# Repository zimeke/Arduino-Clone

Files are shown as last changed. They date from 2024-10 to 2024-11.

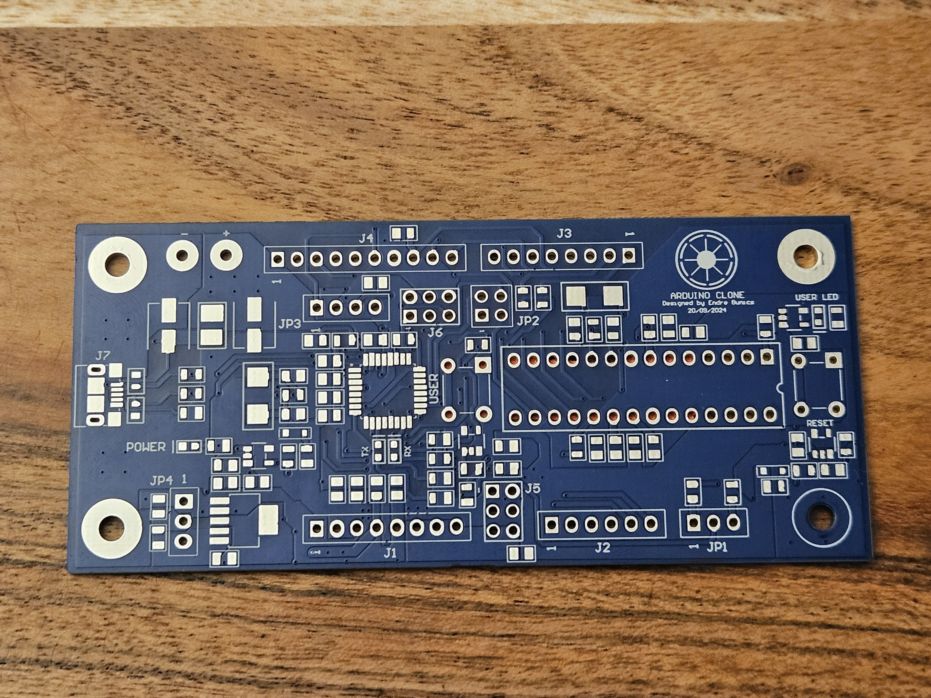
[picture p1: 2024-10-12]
Photos/Arduino Clone without components.jpg

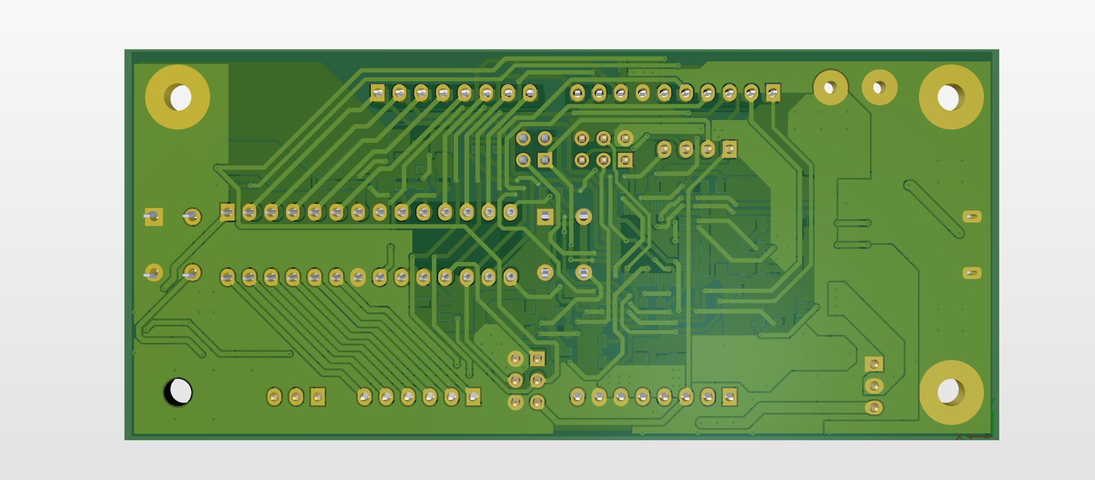
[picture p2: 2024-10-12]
3D_model_back.PNG

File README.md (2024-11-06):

# Arduino Clone
This project involves creating a microcontroller similar to the Arduino UNO. The design and implementation were based on the guidance provided by Robert Feranec (youtube/udemy educator). The project includes PCB layout design using Altium Designer, soldering the components, checking the soldered connections, programming, and testing the microcontroller.

Arduino Clone

## Designing PCB layout and 3D model in Altium Designer

I developed the PCB layout design and the board's 3D model using Altium Designer. All necessary documents for circuit manufacturing have been uploaded to the repository. For guidance on creating the schematic and PCB layout, I followed Robert Feranec's instructional videos.

Link to the guide:
https://www.udemy.com/course/learn-to-design-your-own-boards

3D_model_side
<p align="center">
  3D model in Altium Designer
</p>

## Soldering the components

Arduino Clone without components

<p align="center">
  PCB without components
</p>

After designing the PCB layout, I had the board manufactured by JLCPCB. I ordered the components from Digi-Key, which I soldered on the PCB by hand. For the soldering process, I used the following tools:
* Flux: EDSYN FL 22 R & Stannol 165018 F-SW 26
* Solder: STANNOL HF32
* Tweezers
* Soldering Station: Hakko FX888D
* Soldering Tip: Hakko T18-D24
* Desoldering Wire

(I worked with a soldering iron heated to 350 degrees Celsius.)

 tools
<p align="center">
  Tools used
</p>

Arduino Clone without connectors

I started with the soldering of the ATmega16U2 component, as it proved to be the most challenging. After soldering, I inspected the connections using a magnifying glass to check for any short circuits between the individual pins, followed by verification with a multimeter.

Next, I moved on to soldering smaller components, such as SOD-323 and 0603 size-code components. I used the following method for soldering these components:

1. I first applied a small amount of flux to one pad of the component.
2. Then, I placed solder on that pad.
3. After that, I applied more flux to the pad and soldered the component's corresponding lead on the pad where the solder had previously been applied.
4. Finally, I soldered the other lead(s) of the component.

To check if the component was properly soldered, I pushed one of its leads with the hot soldering iron tip. If the component did not move, it indicated that the other lead was secured, confirming that the connection had been made.

However, this method was not practical, because is some cases the solder mask came off during the pushing process.

After soldering all the components, I checked each soldered connection using a multimeter to ensure that all connections were properly made. Afterward, I soldered the connectors and checked them as well to ensure proper connections. Fortunately, all the soldered joints were correct, so no further adjustments were needed.

Arduino Clone compared to Arduino UNO
<p align="center">
  Arduino Clone compared to Arduino UNO
</p>

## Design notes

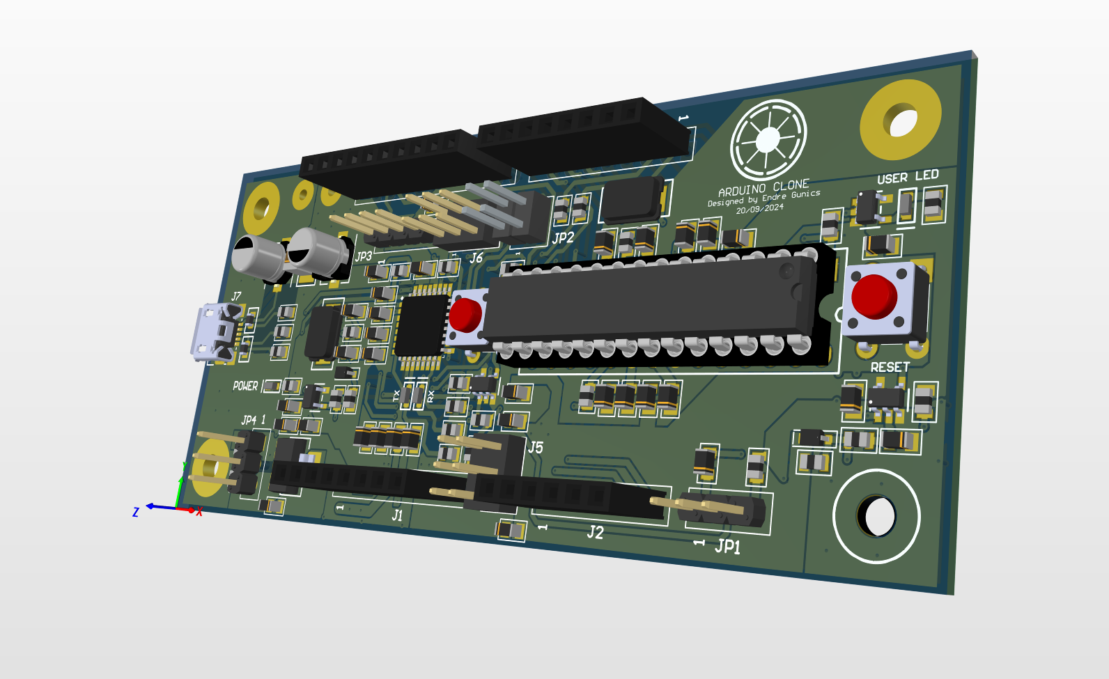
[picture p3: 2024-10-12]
3D_model_side.PNG

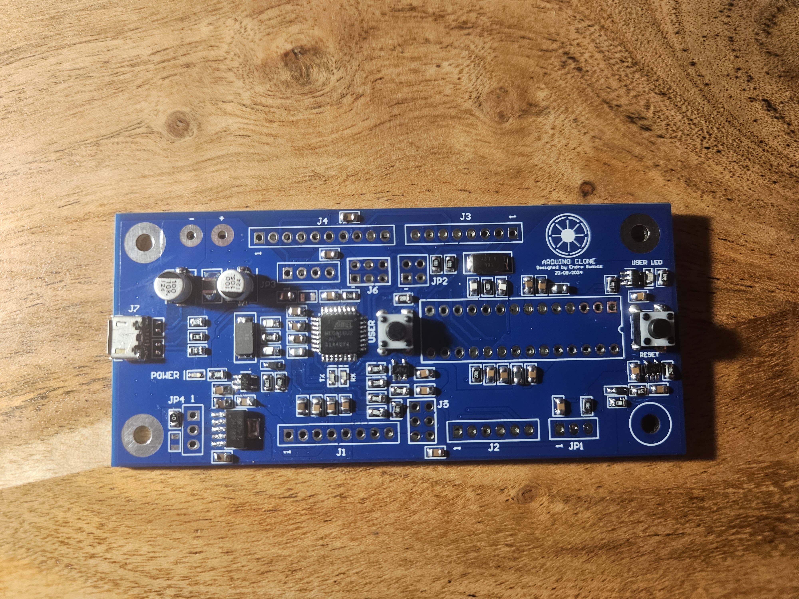
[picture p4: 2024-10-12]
Photos/Arduino Clone without connectors.jpg

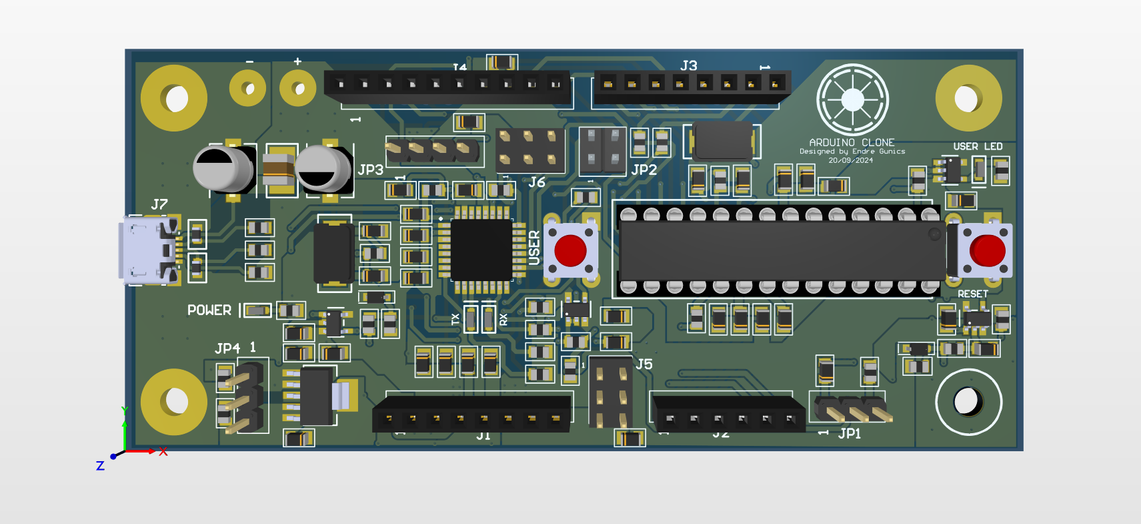
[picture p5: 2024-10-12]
3D_model_front.PNG

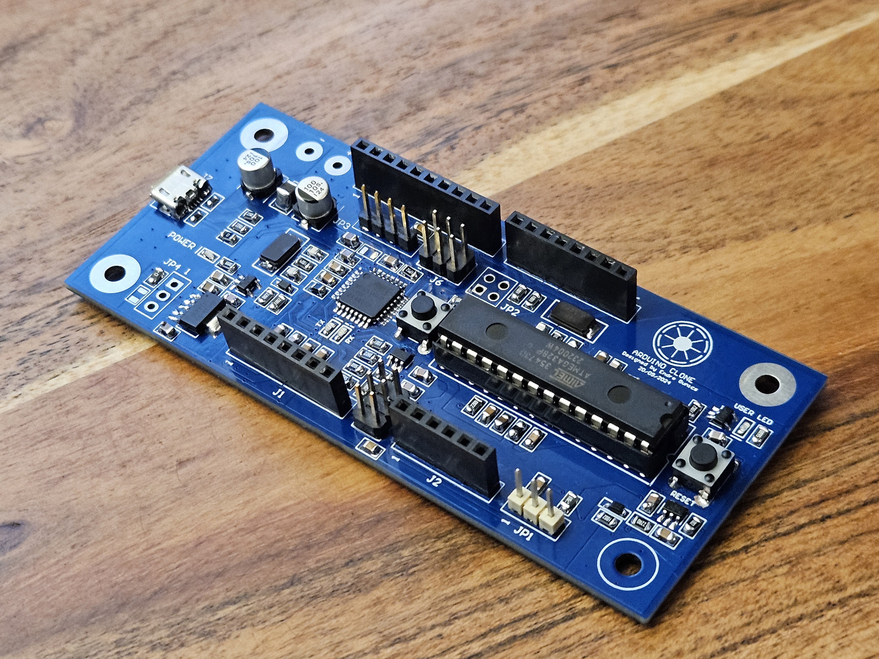
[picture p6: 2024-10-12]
Photos/Arduino Clone.jpg

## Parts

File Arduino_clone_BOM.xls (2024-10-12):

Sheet: Part List Report
# | Designator | Quantity | Comment | Description | Manufacturer 1 | Manufacturer Part Number 1 | Package / Case | Supplier 1 | Supplier Part Number 1 | Quantity
1 | C1, C2 | 2 | 100u / 10V | CAP ALUM 100UF 10V 20% SMD | Panasonic Electronic Components | EEE-1AA101WR | Radial, Can - SMD | Digi-Key | PCE3867CT-ND | 2
2 | C3, C12, C13, C19, C21, C22, C34 | 7 | 10uF / 16V | CAP CER 10UF 16V 20% X5R 0805 | TDK Corporation | C2012X5R1C106M125AC | 0805 (2012 Metric) | Digi-Key | 445-4115-1-ND | 7
3 | C4, C5, C6, C8, C11, C14, C15, C16, C17, C20, C23, C24, C26, C28, C29, C30, C31, C32, C33 | 19 | 100n | CAP CER 0.1UF 50V 10% X7R 0805 | TDK Corporation | C2012X7R1H104K085AA | 0805 (2012 Metric) | Digi-Key | 445-7534-1-ND | 19
4 | C7 | 1 | 1u | CAP CER 1UF 25V 10% X5R 0805 | TDK Corporation | C2012X5R1E105K125AA | 0805 (2012 Metric) | Digi-Key | 445-1419-1-ND | 1
5 | C9, C10, C25, C27 | 4 | 18p | CAP CER 18PF 50V 5% NP0 0805 | Kemet | C0805C180J5GACTU | 0805 (2012 Metric) | Digi-Key | 399-1112-1-ND | 4
6 | D1 | 1 | Green | LED SMARTLED GREEN 570NM 0603 | OSRAM Opto Semiconductors Inc | LG L29K-G2J1-24-Z | 0603 (1608 Metric) | Digi-Key | 475-2709-1-ND | 1
7 | D2, D3, D4 | 3 | Orange | LED SMARTLED ORANGE 606NM 0603 | OSRAM Opto Semiconductors Inc | LO L29K-H2K1-24-Z | 0603 (1608 Metric) | Digi-Key | 475-2740-1-ND | 3
8 | D5, D6 | 2 | BAT54HT1G | DIODE SCHOTTKY 30V 0.2A SOD323 | Fairchild Semiconductor | BAT54HT1G | SC-76, SOD-323 | Digi-Key | BAT54HT1GCT-ND | 2
9 | FB1, FB2, FB3 | 3 | MPZ2012S601AT000 | FERRITE CHIP BEAD 600 OHM SMD | TDK Corporation | MPZ2012S601AT000 | 0805 (2012 Metric) | Digi-Key | 445-2206-1-ND | 3
10 | J1, J3 | 2 | HDR FMALE 1x8 2.54mm | 08-WAY SIL VERT SOCKET L/FREE | Harwin Inc | M20-7820842 |  | Digi-Key | 952-1823-ND | 2
11 | J2 | 1 | HDR FMALE 1x6 2.54mm | 06-WAY SIL VERT SOCKET L/FREE | Harwin Inc | M20-7820646 |  | Digi-Key | 952-1809-ND | 1
12 | J4 | 1 | HDR FMALE 1x10 2.54mm | 10-WAY SIL VERT SOCKET L/FREE | Harwin Inc | M20-7821046 |  | Digi-Key | 952-1847-ND | 1
13 | J5, J6 | 2 | HDR 2x3 | CONN HEADER 6POS .100 STR 30AU | FCI | 67997-106HLF |  | Digi-Key | 609-3393-ND | 2
14 | J7 | 1 | 10118193-0001LF | CONN USB MICRO B RECPT SMT R/A | FCI | 10118193-0001LF |  | Digi-Key | 609-4616-1-ND | 1
15 | JP1, JP4 | 2 | HDR 1x3 | BERGSTIK II .100" SR STRAIGHT | FCI | 68000-103HLF |  | Digi-Key | 609-3461-ND | 2
16 | JP3 | 2 | HDR 1x4 | CONN HEADER 4POS .100 STR 15AU | FCI | 68002-204HLF |  | Digi-Key | 609-3369-ND | 2
17 | JP3 | 2 | HDR 1x4 | CONN HEADER 4POS .100 STR 15AU | FCI | 68001-204HLF |  | Digi-Key | 609-3402-ND | 2
18 | L1 | 1 | 2u2 / 2A | FIXED IND 2.2UH 2A 80 MOHM SMD | Kemet | L1210R2R2MDWIT | 1210 (3225 Metric) | Digi-Key | 399-9598-1-ND | 1
19 | LINK1, LINK2, LINK3 | 3 | LINK | CONN JUMPER SHORTING .100" GOLD | Sullins Connector Solutions | QPC02SXGN-RC |  | Digi-Key | S9337-ND | 3
20 | R1 | 1 | 100k | RES SMD 100K OHM 1% 1/8W 0805 | Yageo | RC0805FR-07100KL | 0805 (2012 Metric) | Digi-Key | 311-100KCRCT-ND | 1
21 | R2, R3, R15, R17, R22 | 5 | 560R | RES SMD 560 OHM 1% 1/8W 0805 | Yageo | RC0805FR-07560RL | 0805 (2012 Metric) | Digi-Key | 311-560CRCT-ND | 5
22 | R4, R14, R18, R19, R20, R21 | 6 | 10k | RES SMD 10K OHM 1% 1/8W 0805 | Yageo | RC0805FR-0710KL | 0805 (2012 Metric) | Digi-Key | 311-10.0KCRCT-ND | 6
23 | R5, R6, R7, R13, R23, R24, R25 | 7 | 22R | RES SMD 22 OHM 1% 1/8W 0805 | Yageo | RC0805FR-0722RL | 0805 (2012 Metric) | Digi-Key | 311-22.0CRCT-ND | 7
24 | R8 | 4 | 0R | RES 0.0 OHM 1/8W 0805 SMD | Yageo | RC0805JR-070RL | 0805 (2012 Metric) | Digi-Key | 311-0.0ARCT-ND | 4
25 | R9, R16 | 2 | 1M | RES SMD 1M OHM 1% 1/8W 0805 | Yageo | RC0805FR-071ML | 0805 (2012 Metric) | Digi-Key | 311-1.00MCRCT-ND | 2
26 | R10, R11, R12 | 3 | 1k | RES SMD 1K OHM 1% 1/8W 0805 | Yageo | RC0805FR-071KL | 0805 (2012 Metric) | Digi-Key | 311-1.00KCRCT-ND | 3
27 | SCKT FOR U1 | 1 | 28-DIP Socket | CONN IC DIP SOCKET 28POS TIN | 3M | 4828-3004-CP |  | Digi-Key | 3M5480-ND | 1
28 | SW1, SW2 | 2 | 1825910-6 | SWITCH TACTILE SPST-NO 0.05A 24V | TE Connectivity | 1825910-6 |  | Digi-Key | 450-1650-ND | 2
29 | U1 | 1 | ATMEGA328P-PU | IC MCU 8BIT 32KB FLASH 28DIP | Atmel | ATMEGA328P-PU | 28-DIP (0.300", 7.62mm) | Digi-Key | ATMEGA328P-PU-ND | 1
30 | U2 | 1 | ATMEGA16U2-AU | IC MCU 8BIT 16KB FLASH 32TQFP | Atmel | ATMEGA16U2-AU | 32-TQFP | Digi-Key | ATMEGA16U2-AU-ND | 1
31 | U3 | 1 | TL1963A-33DCQR | IC REG LDO 3.3V 1.5A SOT223-6 | Texas Instruments | TL1963A-33DCQR | SOT-223-6 | Digi-Key | 296-24534-1-ND | 1
32 | U4, U5, U6, U7 | 4 | SN74AHC1G09DBVR | IC GATE AND SGL 2INP SOT23-5 | Texas Instruments | SN74AHC1G09DBVR | SC-74A, SOT-753 | Digi-Key | 296-29202-1-ND | 4
33 | Y1, Y2 | 2 | ABM7-16.000MHZ-D2Y-T | CRYSTAL 16MHZ 18PF SMD | Abracon LLC | ABM7-16.000MHZ-D2Y-T | 2-SMD | Digi-Key | 535-9840-1-ND | 2
34 | Z1, Z2 | 2 | CG0603MLC-05E | VARISTOR 0603 | Bourns Inc. | CG0603MLC-05E | 0603 (1608 Metric) | Digi-Key | CG0603MLC-05ECT-ND | 2

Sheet: Project Information
Project Full Path | S:\FEDEVEL\28pins\V1I1\28Pins_Project_V1I1.PrjPcb
Project Filename | 28Pins_Project_V1I1.PrjPcb
Variant Name | 5V/3V3
Data-Source Filename | 28Pins_Project_V1I1.PrjPcb
Data-Source Full Path | S:\FEDEVEL\28pins\V1I1\28Pins_Project_V1I1.PrjPcb
Title | 28Pins_Project_V1I1.PrjPcb
Total Quantity | 95
Report Time | 4:53:29 PM
Report Date | 4/7/2015
Report Date & Tine | 4/7/2015 4:53:29 PM
Output Name | 28Pins Component reference grouped BOM
Output Type | BOM_PartType
Output Generator Name | BOM
Output Generator Description | Bill of Materials

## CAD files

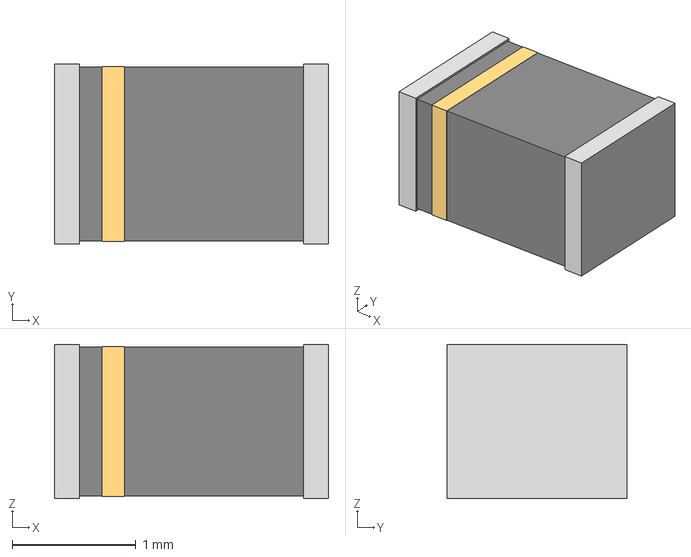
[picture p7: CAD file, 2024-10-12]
3D_models_for_Altium_Designer/CAP_2012_TDK.step
2.21 x 1.45 x 1.25 mm

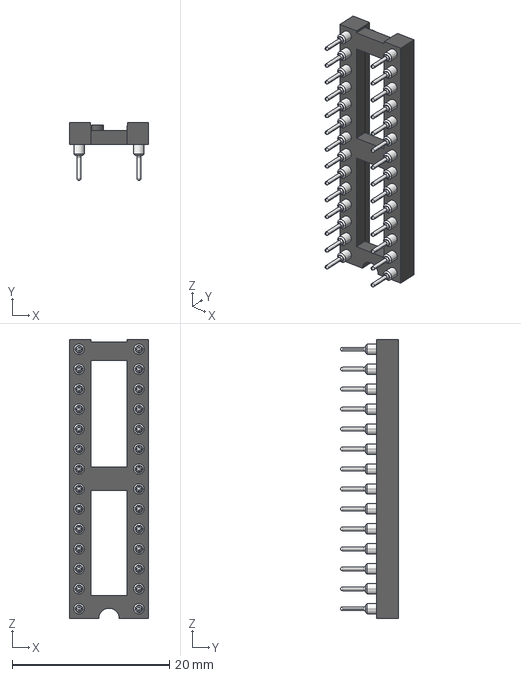
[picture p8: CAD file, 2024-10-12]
3D_models_for_Altium_Designer/dil_socket.stp
10.1 x 7.37 x 35.5 mm

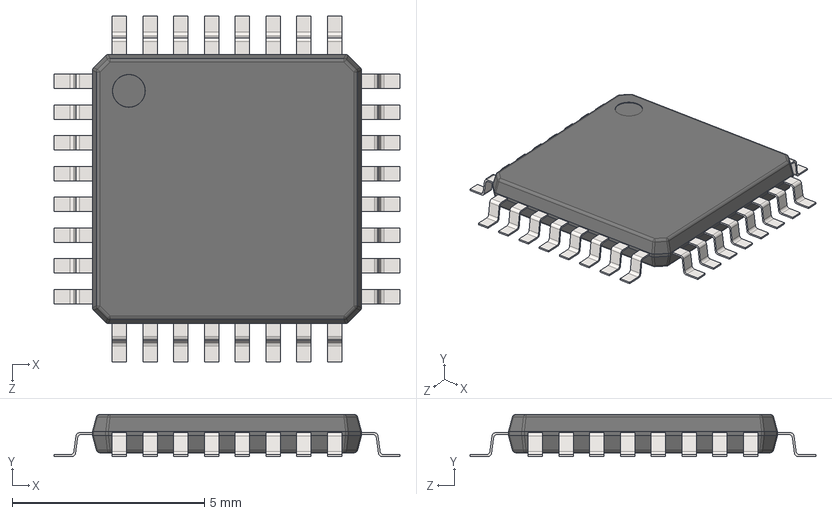
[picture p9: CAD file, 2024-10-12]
3D_models_for_Altium_Designer/TQFP-32.STEP
9.00 x 1.10 x 9.00 mm

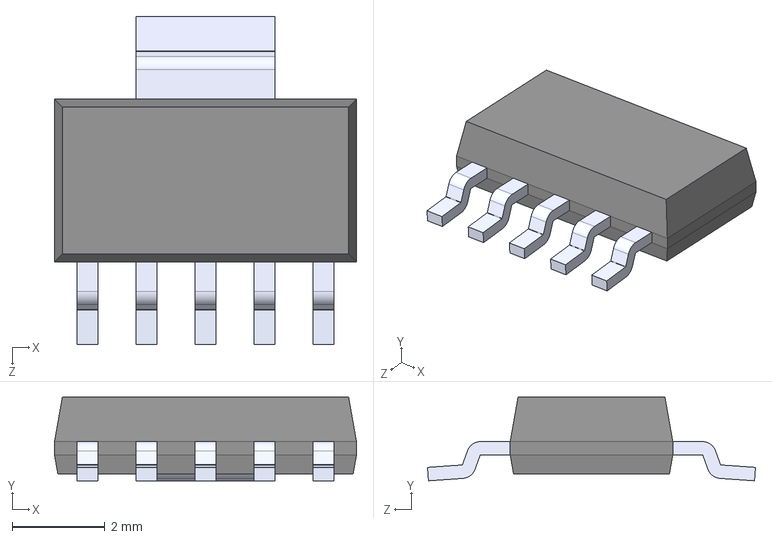
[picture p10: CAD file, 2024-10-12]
3D_models_for_Altium_Designer/TL1963A-33DCQR.step
6.50 x 1.80 x 7.06 mm

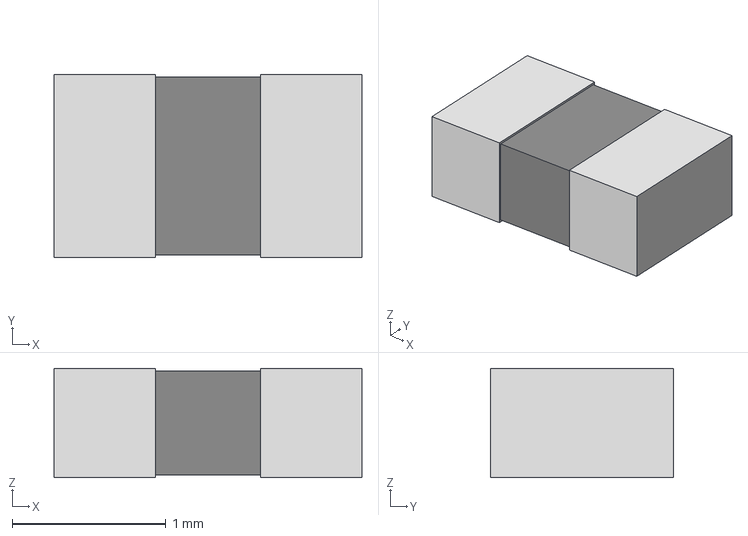
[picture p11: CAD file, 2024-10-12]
3D_models_for_Altium_Designer/RC0805N_YAG.step
2.01 x 1.19 x 0.711 mm

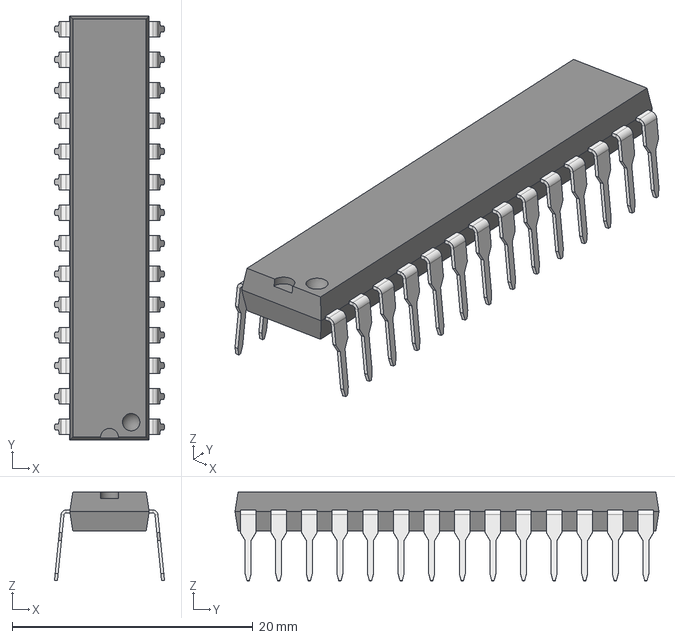
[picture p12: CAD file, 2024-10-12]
3D_models_for_Altium_Designer/DIP-28 N.step
9.14 x 35.2 x 7.35 mm

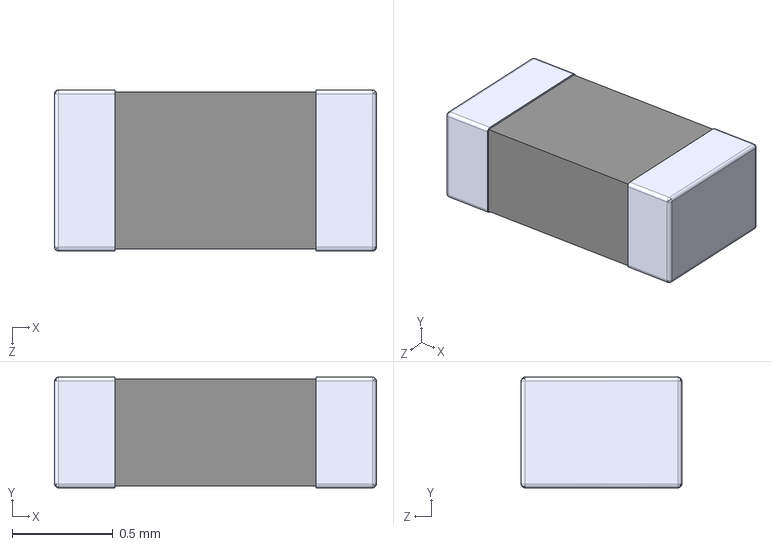
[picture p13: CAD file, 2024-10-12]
3D_models_for_Altium_Designer/CG0603MLC-05E.step
1.60 x 0.55 x 0.8 mm

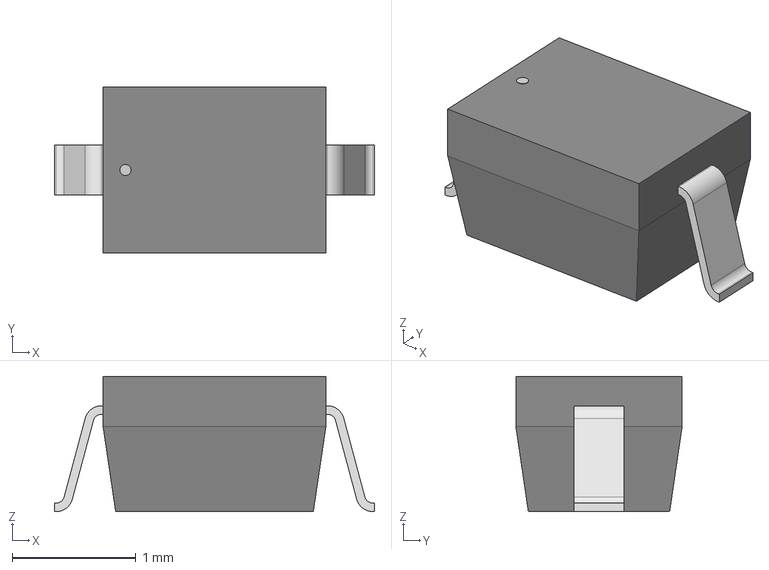
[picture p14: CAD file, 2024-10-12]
3D_models_for_Altium_Designer/CR_SOD-323_2L_ONS.step
2.59 x 1.35 x 1.09 mm

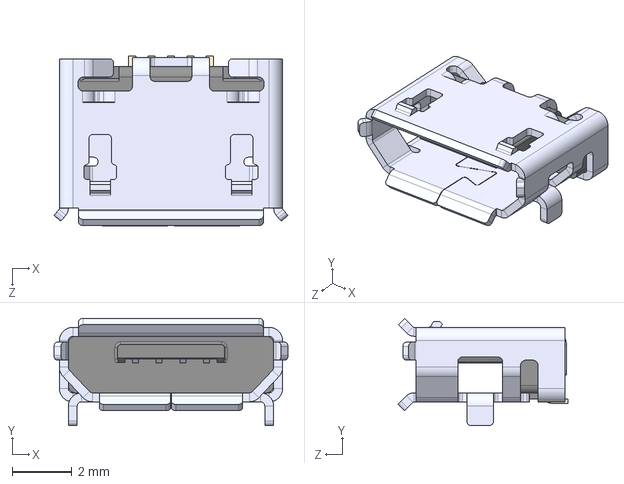
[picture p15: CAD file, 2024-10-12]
3D_models_for_Altium_Designer/USBmicro.step
7.86 x 3.60 x 5.71 mm

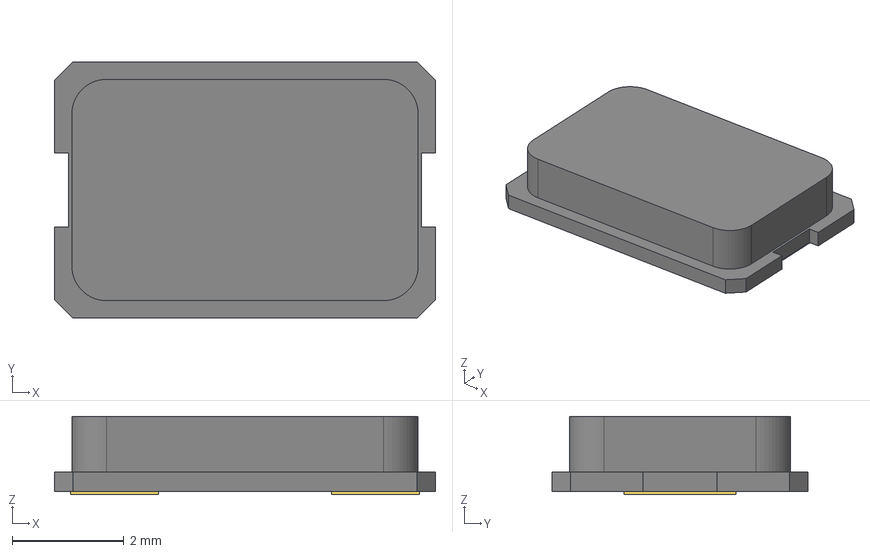
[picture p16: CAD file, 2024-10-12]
3D_models_for_Altium_Designer/XTAL_ABM7_ABR.step
6.82 x 4.58 x 1.40 mm

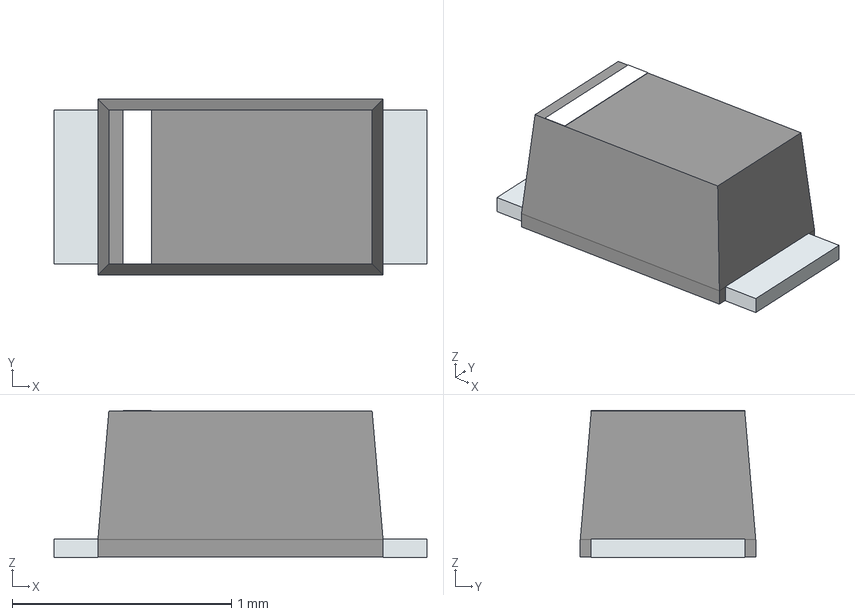
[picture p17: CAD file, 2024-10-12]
3D_models_for_Altium_Designer/LO_L29K-H2K1-24-Z.stp
1.70 x 0.8 x 0.67 mm
PinKIdent
PinK
PinA

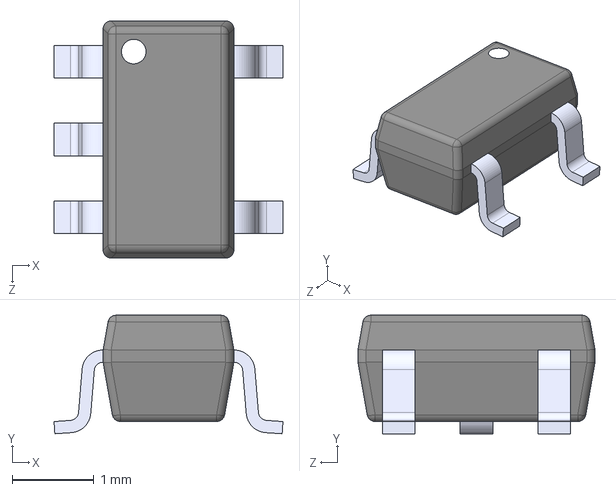
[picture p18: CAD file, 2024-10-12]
3D_models_for_Altium_Designer/SN74AHC1G09DBVR.step
2.80 x 1.45 x 2.90 mm

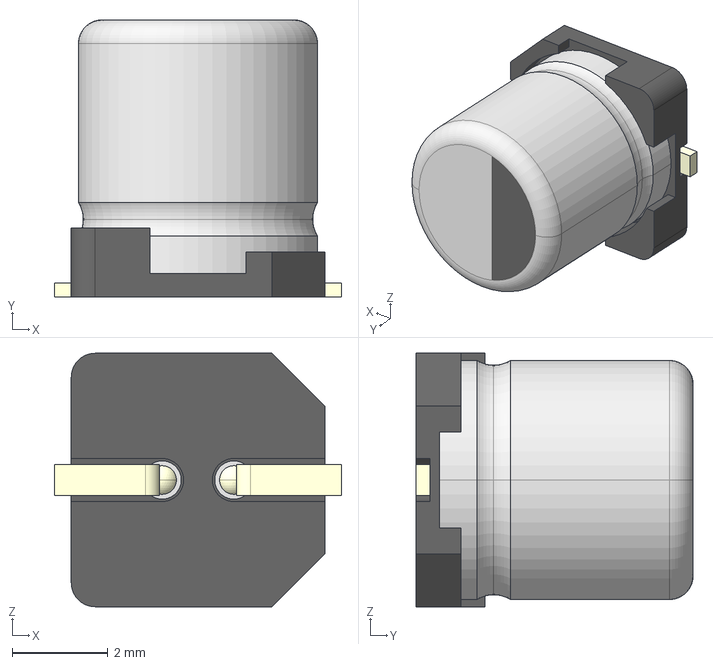
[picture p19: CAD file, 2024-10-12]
3D_models_for_Altium_Designer/5 SIZE CODE C.stp
6.00 x 5.80 x 5.30 mm

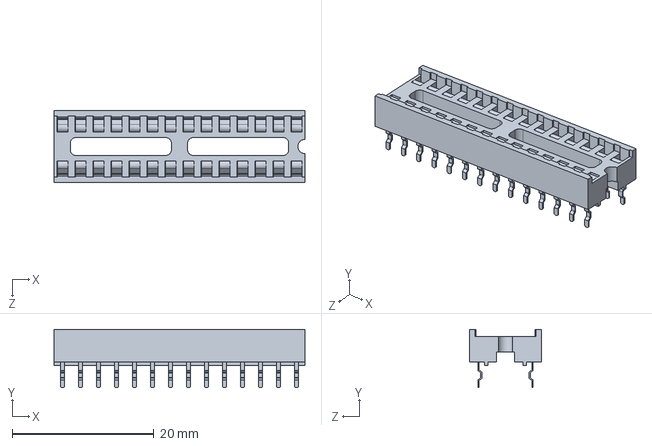
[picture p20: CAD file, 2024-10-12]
3D_models_for_Altium_Designer/4828-3004-CP.stp
35.4 x 8.23 x 10.2 mm

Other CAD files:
3D_models_for_Altium_Designer/M20-7821046_asm.stp
3D_models_for_Altium_Designer/67997-106HLF.step
3D_models_for_Altium_Designer/m20-7820646.stp
3D_models_for_Altium_Designer/1825910-6.step
3D_models_for_Altium_Designer/68000-103HLF.step
3D_models_for_Altium_Designer/68001-204HLF.step
3D_models_for_Altium_Designer/68602-204HLF.stp
3D_models_for_Altium_Designer/m20-7820842.stp

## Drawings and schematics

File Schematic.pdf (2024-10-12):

# 8 HDR FMALE 1x8 2.54mm J1

NF

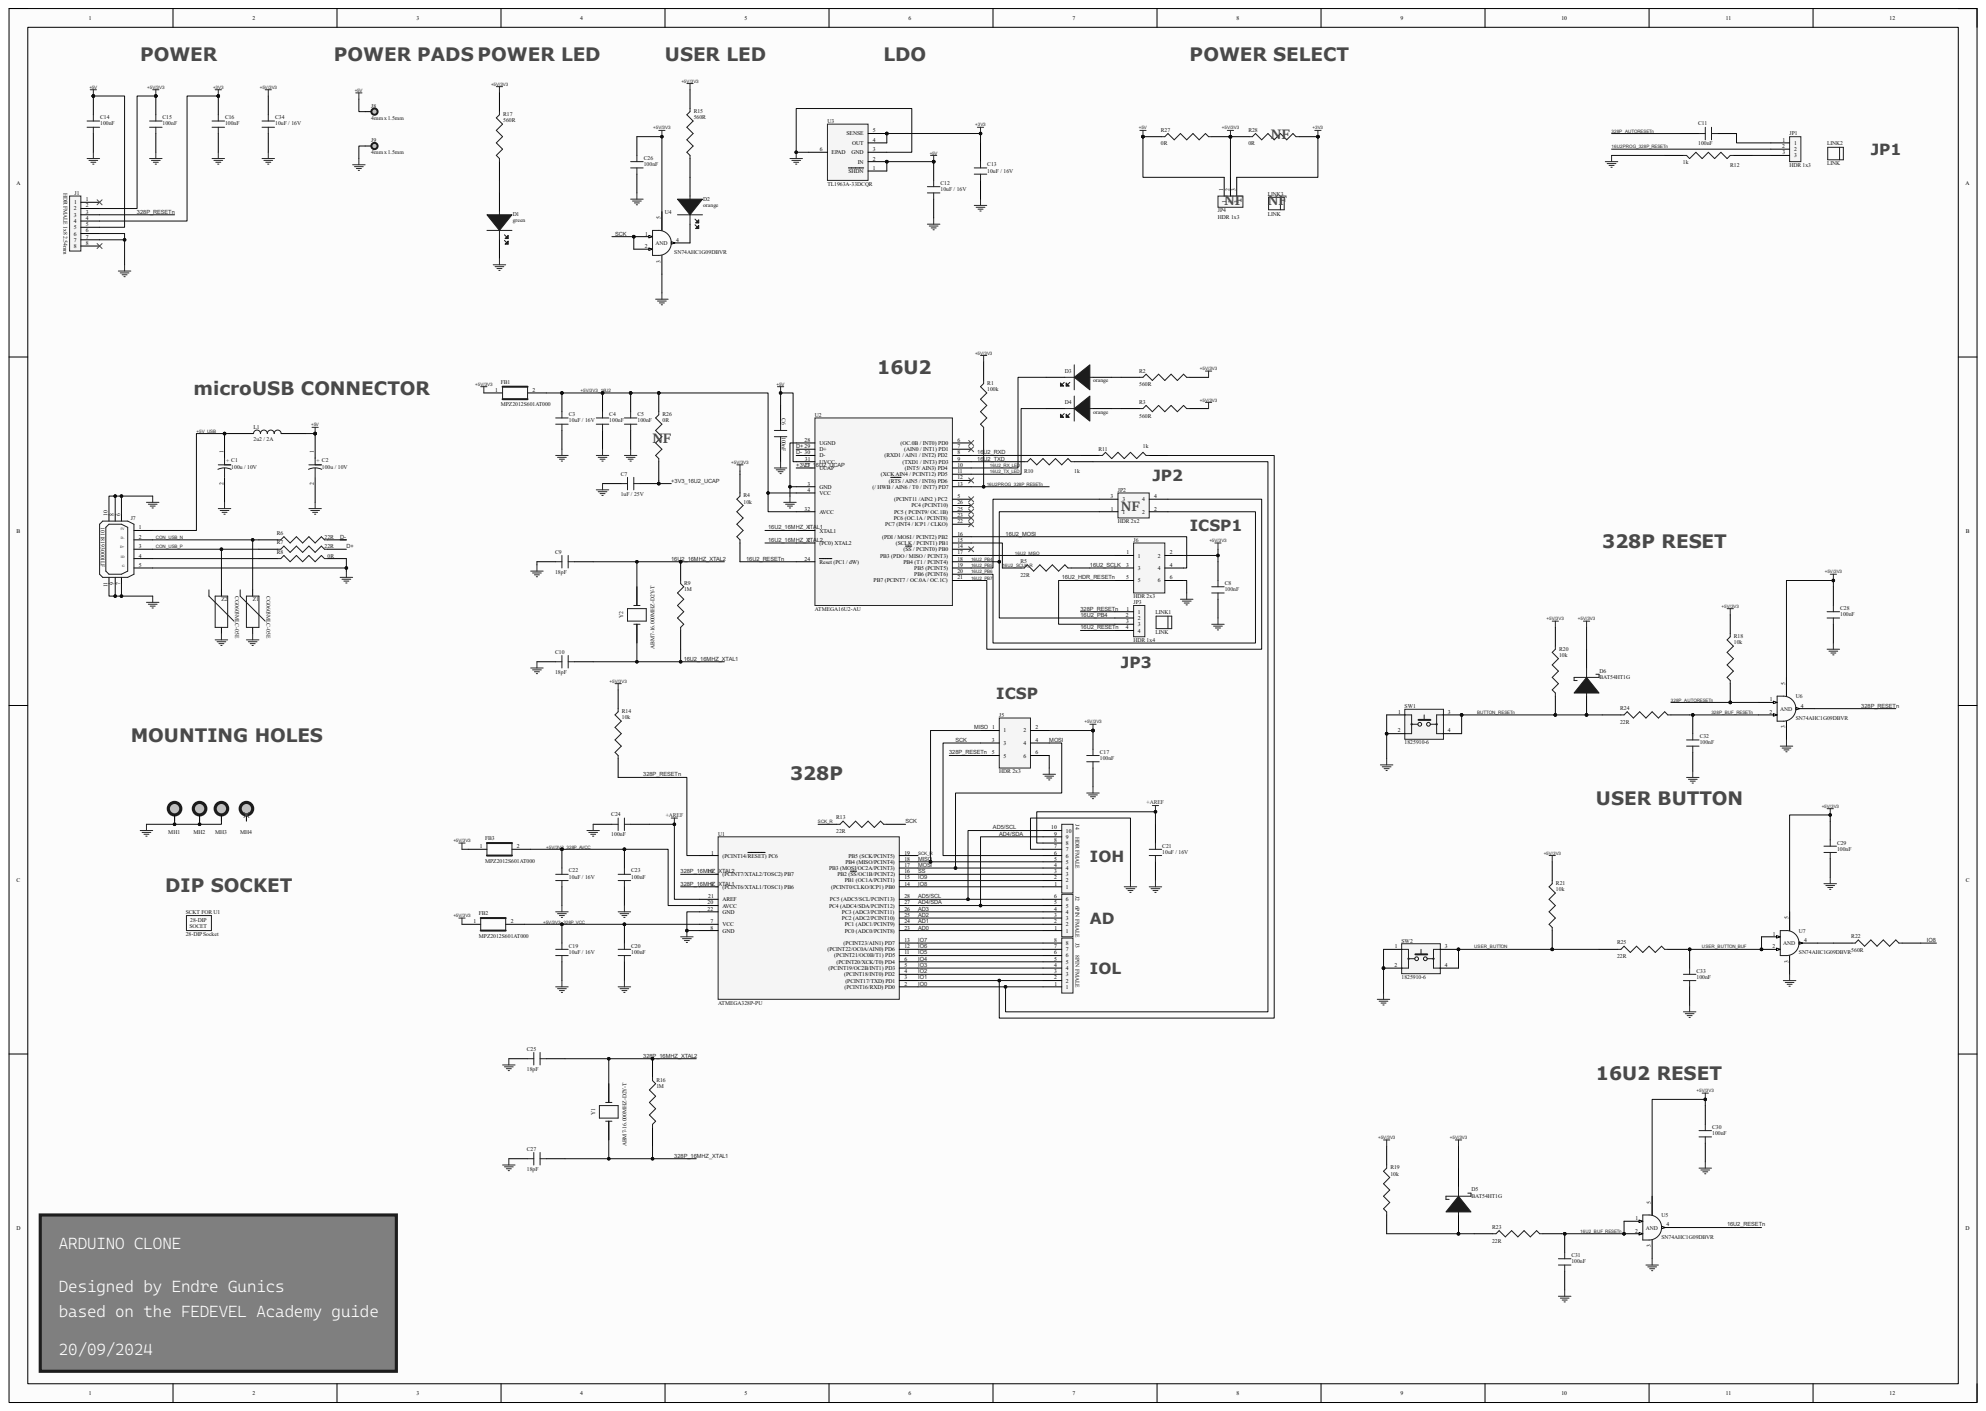
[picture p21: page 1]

Designed by Endre Gunics
based on the FEDEVEL Academy guide

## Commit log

2024-10-12 Rename 20241011_215348.jpg to Arduino Clone without connectors.jpg
2024-10-12 Update and rename Arduino Clone withount connectors.jpg to Arduino Clone without connectors.jpg
2024-10-12 Rename 20241012_134726.jpg to Arduino Clone without components.jpg
2024-10-12 Rename 20241012_001412.jpg to Arduino Clone.jpg
2024-10-12 Rename 20241012_001330.jpg to Arduino UNO and Arduino Clone.jpg
